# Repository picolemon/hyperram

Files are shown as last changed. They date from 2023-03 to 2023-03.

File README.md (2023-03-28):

# HyperRAM PMOD :lemon: # 








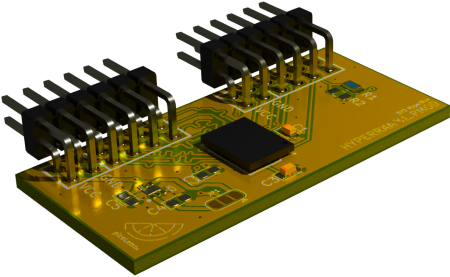
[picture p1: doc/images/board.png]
HyperRam board overview


### Overview :hammer:
HyperRam board for use with PMOD compatible FPGA devices. This repo contains the
example RTL code, datasheets and schematics for the device.

### Whats included :musical_note:
- [x] Example wishbone memory controller.
- [x] Memory tester to validate the device works.
- [x] [Schematic](doc/sch.pdf), [PCB](pcb/) and [BOM](https://htmlpreview.github.io/?https://github.com/picolemon/hyperram/blob/main/doc/ibom.html).

### Getting started :mag:
Read the [datasheet](doc/datasheet.pdf) and run the [example](examples/) project.

### Support :zap:
- Drop by the [discord](https://discord.gg/Be3yFCzyrp)
- Email help@picolemon.com

### License :penguin:
 
The MIT License (MIT)

Copyright (c) 2023 picoLemon

Permission is hereby granted, free of charge, to any person obtaining a copy of this software and associated documentation files (the "Software"), to deal in the Software without restriction, including without limitation the rights to use, copy, modify, merge, publish, distribute, sublicense, and/or sell copies of the Software, and to permit persons to whom the Software is furnished to do so, subject to the following conditions:

The above copyright notice and this permission notice shall be included in all copies or substantial portions of the Software.

THE SOFTWARE IS PROVIDED "AS IS", WITHOUT WARRANTY OF ANY KIND, EXPRESS OR IMPLIED, INCLUDING BUT NOT LIMITED TO THE WARRANTIES OF MERCHANTABILITY, FITNESS FOR A PARTICULAR PURPOSE AND NONINFRINGEMENT. IN NO EVENT SHALL THE AUTHORS OR COPYRIGHT HOLDERS BE LIABLE FOR ANY CLAIM, DAMAGES OR OTHER LIABILITY, WHETHER IN AN ACTION OF CONTRACT, TORT OR OTHERWISE, ARISING FROM, OUT OF OR IN CONNECTION WITH THE SOFTWARE OR THE USE OR OTHER DEALINGS IN THE SOFTWARE.

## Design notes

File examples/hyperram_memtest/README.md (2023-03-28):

# HyperRam_memTest :lemon: # 

### Description :books:
A Very simple HyperRam memory tester to verify the device is functional. Once the device has reset and setup the state machine writes a single value into memory and reads back then to confirm the bus is functional.

### Features :rocket:
- [x] Very basic controller, doesnt use any ODDR instances for portability at the expense of speed.
- [x] Wishbone memory controller initializes the device and allow read/write of 32bit wide bus.
- [x] Full test-bench available ( separate model downloadable separately for licensing ).
- [x] Vivado & Lattice project templates.
- [x] Test state via led & UART.

### Getting started :car:
- Open examples/hyperram_memtest test project in Vivado or Diamond.
- Setup board constraints to match pins in the [datasheet](../../docs/datasheet.pdf).
- Add status led & UART to constraints to get test output.
- Optionally run Vivado simulation.
- Run memory tester and wait for led to light solid, it will either not respond or flash for an error detected.

### Project overview :mag:

* **vhd/**
  * Main project RTL source which contains the main memory tester and stubs for platform specifics such as clock/pll generators.
* **vivado/**
	* Xilinx project files 
* **vivado/vhd**
	* Xilinx specific implementation for example clock PLLs are instanced in clocks.impl.vhd.
* **vivado/test**
	* Vivado simulation of ram tester. Note the simulation will fail until the [Infineon model](https://www.infineon.com/dgdl/Infineon-S27KL0641_S27KS0641_VERILOG-SimulationModels-v05_00-EN.zip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) as been downloaded and added to the project,
	this is not included and must be downloaded separately. To setup, download the model then extract the S27kl0641.exe using 7zip ( or optionally run the exe if using Windows/wine ), then copy "S27kl0641\model\s27kl0641.v" to "vivado/test/s27kl0641.v".

* **diamond/**
	* Lattice diamond project file.

* **apio/**
	* [apio](https://github.com/FPGAwars/apio) project.
* **apio/build.sh**
	* Translates vhd to verilog ( required for apio ).
* **apio/vhd**
	* Apio specific top level and Lattice specific clocks.

### Software dependencies :loop:
- HyperRAM Simulation model:	https://www.infineon.com/dgdl/Infineon-S27KL0641_S27KS0641_VERILOG-SimulationModels-v05_00-EN.zip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
- Vivado Vivado 2019.2 or greater.
- Diamond 3.12 or greater.

### Tested devices
- [Arty-S7-50](https://projects.digilentinc.com/products/arty-s7-50)

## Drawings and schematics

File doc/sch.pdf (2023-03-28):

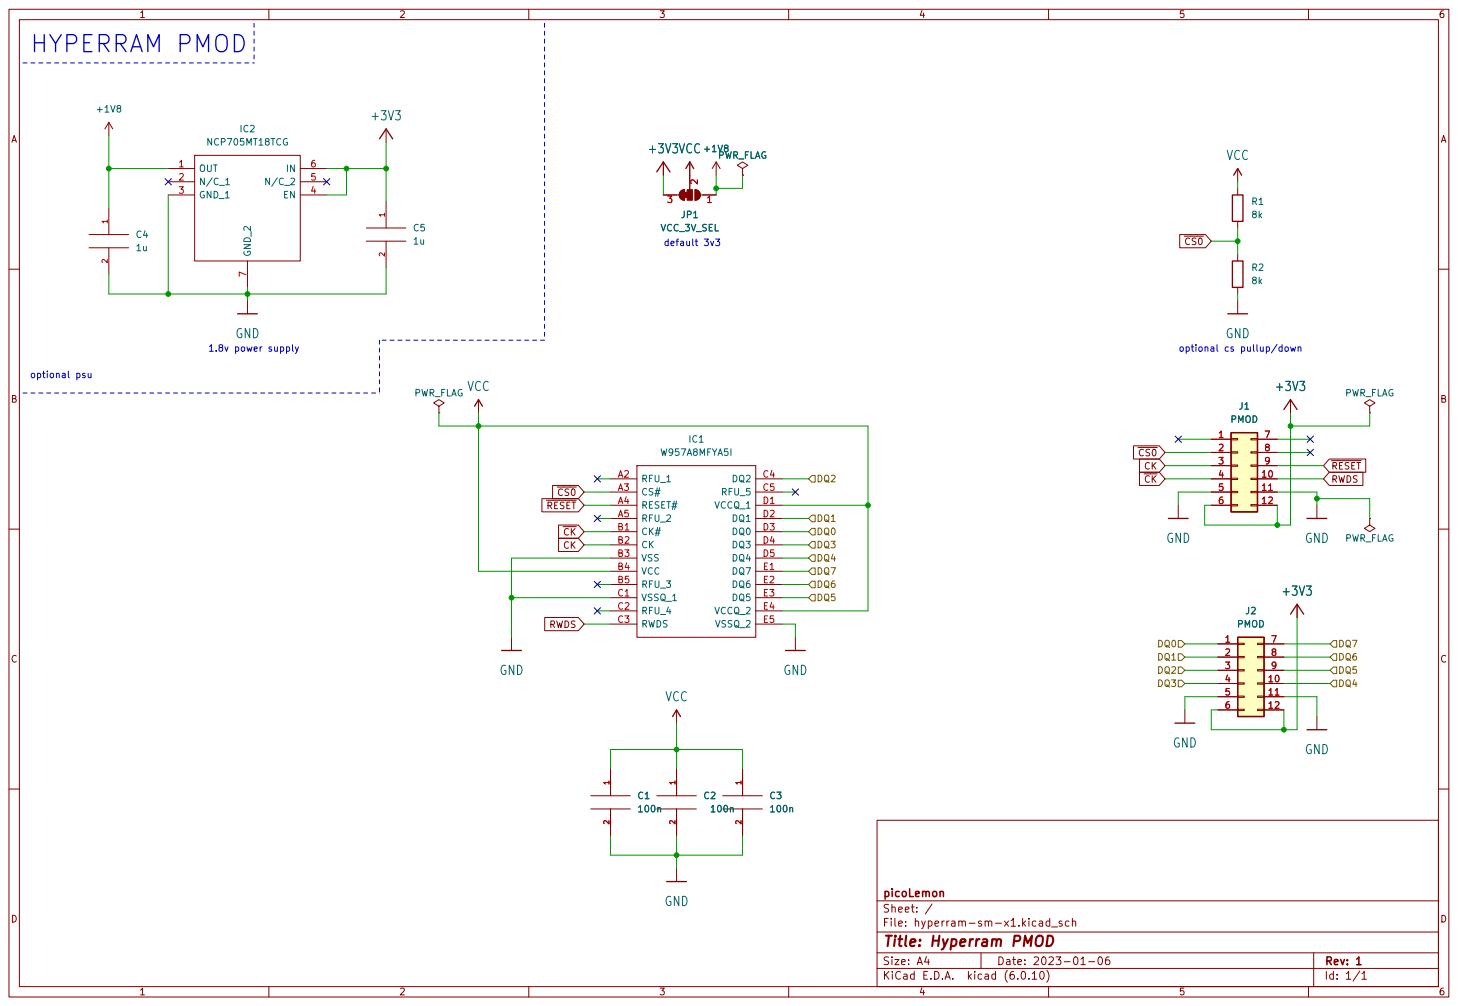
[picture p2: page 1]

File: hyperram-sm-x1.kicad_sch Sheet: / picoLemon

Id: 1/1 Title: Hyperram PMOD

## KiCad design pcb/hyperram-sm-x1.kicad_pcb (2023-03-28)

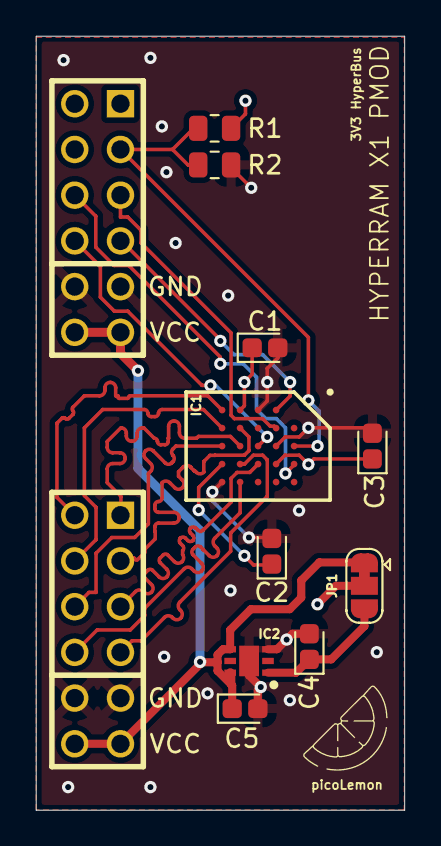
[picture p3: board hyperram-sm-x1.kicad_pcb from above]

Board: 4 copper layers, 20.5 x 43.0 mm, 12 parts (0 on the bottom side), 17 nets.

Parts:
C1, C2, C3: 100n; CP_EIA-1608-08_AVX-J
C4, C5: 1u; CP_EIA-1608-08_AVX-J
IC1: W957A8MFYA5I; BGA24C100P5X5_600X800X120
IC2: NCP705MT18TCG; SON65P200X200X80-7N
J1, J2: PMOD; pmod_pin_array_6x2
JP1: VCC_3V_SEL; SolderJumper-3_P1.3mm_Bridged23_RoundedPad1.0x1.5mm
R1, R2: 8k; R_0805_2012Metric

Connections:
+1V8: C4.1, IC2.1 (OUT), JP1.1 (A)
+3V3: C5.1, IC2.4 (EN), IC2.6 (IN), J1.6, J1.12, J2.6, J2.12, JP1.3 (B)
/DQ0: IC1.D3 (DQ0), J2.1
/DQ1: IC1.D2 (DQ1), J2.2
/DQ2: IC1.C4 (DQ2), J2.3
/DQ3: IC1.D4 (DQ3), J2.4
/DQ4: IC1.D5 (DQ4), J2.10
/DQ5: IC1.E3 (DQ5), J2.9
/DQ6: IC1.E2 (DQ6), J2.8
/DQ7: IC1.E1 (DQ7), J2.7
CK: IC1.B2 (CK), J1.3
GND: C1.2, C2.2, C3.2, C4.2, C5.2, IC1.B3 (VSS), IC1.C1 (VSSQ_1), IC1.E5 (VSSQ_2), IC2.3 (GND_1), IC2.7 (GND_2), J1.5, J1.11, J2.5, J2.11, R2.2
RWDS: IC1.C3 (RWDS), J1.10
VCC: C1.1, C2.1, C3.1, IC1.B4 (VCC), IC1.D1 (VCCQ_1), IC1.E4 (VCCQ_2), JP1.2 (C), R1.1
~CK: IC1.B1 (CK#), J1.4
~CS0: IC1.A3 (CS#), J1.2, R1.2, R2.1
~RESET: IC1.A4 (RESET#), J1.9

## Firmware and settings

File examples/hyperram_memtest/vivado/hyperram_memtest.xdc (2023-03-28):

# Example Arty-S7-50 constraints

# clocks
set_property -dict { PACKAGE_PIN R2    IOSTANDARD SSTL135 } [get_ports { clk_i }];
create_clock -add -name sys_clk_pin -period 10.000 -waveform {0 5.000}  [get_ports { clk_i }];

# Debug led
set_property -dict {PACKAGE_PIN E18 IOSTANDARD LVCMOS33} [get_ports {led[0]}]
set_property -dict {PACKAGE_PIN F13 IOSTANDARD LVCMOS33} [get_ports {led[1]}]
set_property -dict {PACKAGE_PIN E13 IOSTANDARD LVCMOS33} [get_ports {led[2]}]
set_property -dict {PACKAGE_PIN H15 IOSTANDARD LVCMOS33} [get_ports {led[3]}]

## USB-UART
set_property -dict {PACKAGE_PIN R12 IOSTANDARD LVCMOS33} [get_ports uart0_txd_o]
set_property -dict {PACKAGE_PIN V12 IOSTANDARD LVCMOS33} [get_ports uart0_rxd_i]

## HyperRAM connected to Arty-S7-50 PMOD PA & PB
set_property PACKAGE_PIN M18 [get_ports hr_resetn]
set_property IOSTANDARD LVCMOS33 [get_ports hr_resetn]
set_property -dict {PACKAGE_PIN L18 IOSTANDARD LVCMOS33} [get_ports hr_csn]
set_property PACKAGE_PIN M14 [get_ports hr_ck]
set_property IOSTANDARD LVCMOS33 [get_ports hr_ck]
set_property SLEW FAST [get_ports hr_ck]
set_property DRIVE 8 [get_ports hr_ck]
set_property PACKAGE_PIN N14 [get_ports hr_ckn]
set_property IOSTANDARD LVCMOS33 [get_ports hr_ckn]
set_property SLEW FAST [get_ports hr_ckn]
set_property DRIVE 8 [get_ports hr_ckn]
set_property PACKAGE_PIN N18 [get_ports hr_rwds]
set_property IOSTANDARD LVCMOS33 [get_ports hr_rwds]
set_property SLEW FAST [get_ports hr_rwds]
set_property DRIVE 8 [get_ports hr_rwds]

set_property PACKAGE_PIN P17 [get_ports {hr_dq[0]}]
set_property IOSTANDARD LVCMOS33 [get_ports {hr_dq[0]}]
set_property SLEW FAST [get_ports {hr_dq[0]}]
set_property DRIVE 8 [get_ports {hr_dq[0]}]
set_property PACKAGE_PIN P18 [get_ports {hr_dq[1]}]
set_property IOSTANDARD LVCMOS33 [get_ports {hr_dq[1]}]
set_property SLEW FAST [get_ports {hr_dq[1]}]
set_property DRIVE 8 [get_ports {hr_dq[1]}]
set_property PACKAGE_PIN R18 [get_ports {hr_dq[2]}]
set_property IOSTANDARD LVCMOS33 [get_ports {hr_dq[2]}]
set_property SLEW FAST [get_ports {hr_dq[2]}]
set_property DRIVE 8 [get_ports {hr_dq[2]}]
set_property PACKAGE_PIN T18 [get_ports {hr_dq[3]}]
set_property IOSTANDARD LVCMOS33 [get_ports {hr_dq[3]}]
set_property SLEW FAST [get_ports {hr_dq[3]}]
set_property DRIVE 8 [get_ports {hr_dq[3]}]
set_property PACKAGE_PIN P16 [get_ports {hr_dq[4]}]
set_property IOSTANDARD LVCMOS33 [get_ports {hr_dq[4]}]
set_property SLEW FAST [get_ports {hr_dq[4]}]
set_property DRIVE 8 [get_ports {hr_dq[4]}]
set_property PACKAGE_PIN N15 [get_ports {hr_dq[5]}]
set_property IOSTANDARD LVCMOS33 [get_ports {hr_dq[5]}]
set_property SLEW FAST [get_ports {hr_dq[5]}]
set_property DRIVE 8 [get_ports {hr_dq[5]}]
set_property PACKAGE_PIN P15 [get_ports {hr_dq[6]}]
set_property IOSTANDARD LVCMOS33 [get_ports {hr_dq[6]}]
set_property SLEW FAST [get_ports {hr_dq[6]}]
set_property DRIVE 8 [get_ports {hr_dq[6]}]
set_property PACKAGE_PIN P14 [get_ports {hr_dq[7]}]
set_property IOSTANDARD LVCMOS33 [get_ports {hr_dq[7]}]
set_property SLEW FAST [get_ports {hr_dq[7]}]
set_property DRIVE 8 [get_ports {hr_dq[7]}]
